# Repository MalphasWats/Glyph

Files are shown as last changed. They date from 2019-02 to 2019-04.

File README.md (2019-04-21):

# Glyph

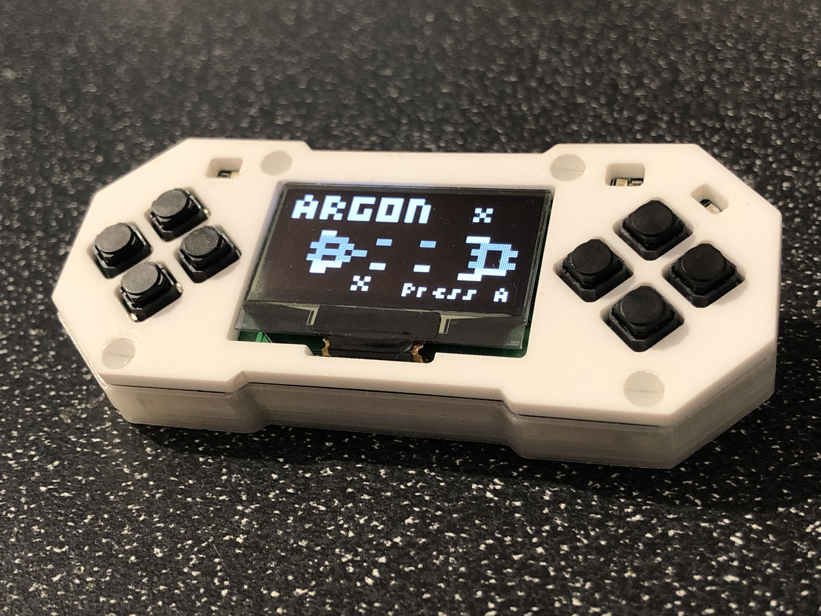
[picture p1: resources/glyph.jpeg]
Glyph


Glyph is a handheld gaming device based on the ATMega1284P micro controller.

This repository contains the mechanical components - KiCAD PCB & laser cut case.

## Specification

* ATMega1284P @ 16MHz. 128kB Flash, 16kB SRAM
* 1.3" monochrome OLED display
* 8 soft buttons
* 2 channel sound via piezo speaker
* 2 programmable red LEDs

## PCB

[KiCAD symbol/footprint library][KiLIB]

## Code

A software library for controlling the hardware and building simple games is available here:

[glyphlib][GLYPHLIB]

## Games

* [Argon][ARGON]
* ... more soon

[GLYPH]: resources/glyph.jpeg
[GLYPHLIB]: https://github.com/MalphasWats/glyphlib
[ARGON]: https://github.com/MalphasWats/Argon
[KiLIB]: https://github.com/MalphasWats/KiCADLib

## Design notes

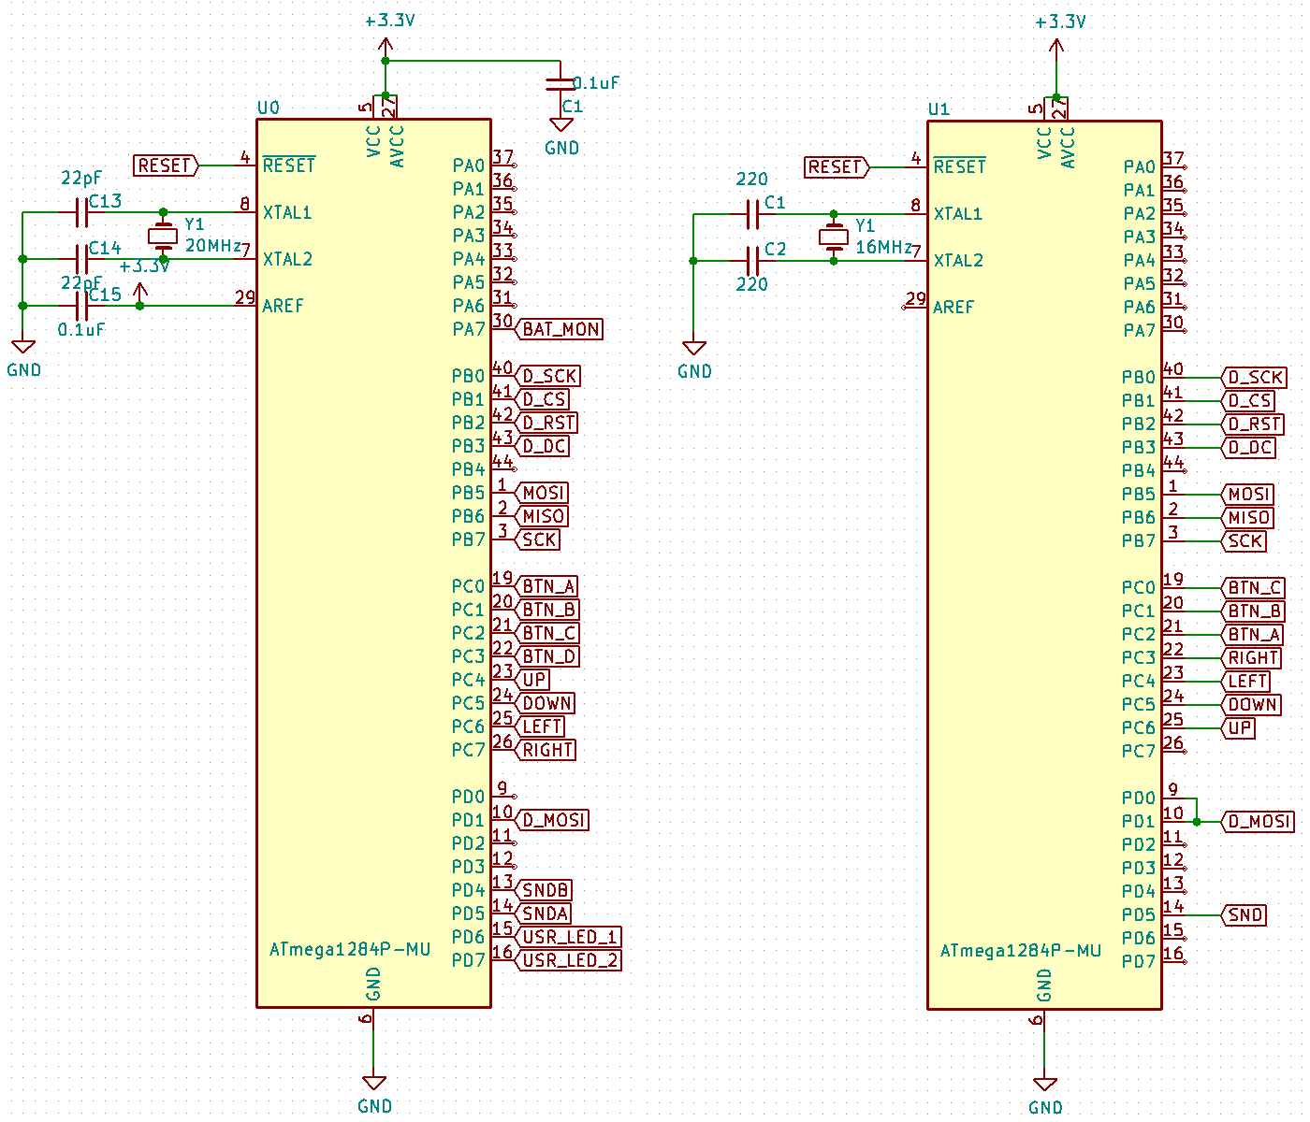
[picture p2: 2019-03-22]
resources/pin-diffs.png

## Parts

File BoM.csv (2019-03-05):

Id | Designator | Package | Quantity | Designation | Supplier and ref
1 | SW9 | ALPS-SSSS811101_SPDT | 1 | POWER
2 | J1 | ISP_SMD | 1 | ISP
3 | U1 | 1.3-OLED-bare-noslot | 1 | 1.3-OLED
4 | SW7 | SW_SOFT_SMD_6mm | 1 | BTN_C
5 | SW0 | SW_SOFT_SMD_6mm | 1 | RESET
6 | SW1 | SW_SOFT_SMD_6mm | 1 | UP
7 | SW2 | SW_SOFT_SMD_6mm | 1 | DOWN
8 | SW3 | SW_SOFT_SMD_6mm | 1 | LEFT
9 | SW4 | SW_SOFT_SMD_6mm | 1 | RIGHT
10 | SW5 | SW_SOFT_SMD_6mm | 1 | BTN_A
11 | SW6 | SW_SOFT_SMD_6mm | 1 | BTN_B
12 | J2 | USB_Micro-B_Molex-105017-0001 | 1 | USB-Micro
13 | LS1 | Generic_Speaker | 1 | Speaker
14 | U2 | SOT-23-5_HandSoldering | 1 | CHG CTRL
15 | U3 | SOT-23_Handsoldering | 1 | Reg
16 | J3 | M2_SCREW_HOLE | 1 | Screw Point 1
17 | J4 | M2_SCREW_HOLE | 1 | Screw Point 2
18 | J5 | M2_SCREW_HOLE | 1 | Screw Point 3
19 | J6 | M2_SCREW_HOLE | 1 | Screw Point 4
20 | SW8 | SW_SOFT_SMD_6mm | 1 | BTN_D
21 | J0 | 150mAh-Lipo | 1 | Battery Pads
22 | C2,C3,C4,C10,C11 | C_0805_2012Metric | 5 | 1uF
23 | C5,C6 | C_0805_2012Metric | 2 | 4.7uF
24 | C7,C12 | C_0805_2012Metric | 2 | 0.1uF
25 | C8 | C_0805_2012Metric | 1 | 47uF
26 | C9 | C_0805_2012Metric | 1 | 22uF
27 | D1 | LED_0805_2012Metric | 1 | USR_1
28 | D2 | LED_0805_2012Metric | 1 | USR_2
29 | R0 | R_0805_2012Metric | 1 | 1K
30 | R1,R6,R7 | R_0805_2012Metric | 3 | LED
31 | R2 | R_0805_2012Metric | 1 | 2K
32 | R3,R4 | R_0805_2012Metric | 2 | 10M
33 | R5 | R_0805_2012Metric | 1 | 290k
34 | C1,C15 | C_0805_2012Metric_Pad1.15x1.40mm_HandSolder | 2 | 0.1uF
35 | C13,C14 | C_0805_2012Metric_Pad1.15x1.40mm_HandSolder | 2 | 22pF
36 | D0 | LED_0805_2012Metric | 1 | CHG
37 | U0 | TQFP-44_10x10mm_P0.8mm | 1 | ATmega1284P-MU
38 | Y1 | Crystal_SMD_5032-2Pin_5.0x3.2mm | 1 | 20MHz

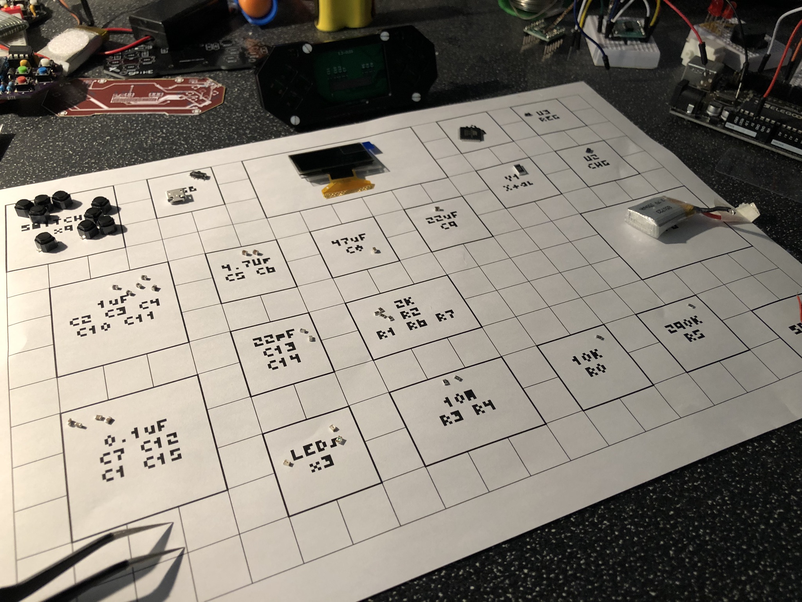
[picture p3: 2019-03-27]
resources/parts.jpeg

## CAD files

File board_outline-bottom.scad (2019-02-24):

module spike()
{
    minkowski()
    {
        union()
        {
            rotate([0, 0, 360/16]) circle(r=18, $fn=8);
            translate([50, 0, 0]) rotate([0, 0, 360/16]) circle(r=18, $fn=8);
            translate([25, 0]) square([32, 30], center=true);
        }
        circle(r=1, $fn=60);
    }
}

module shard()
{
    union()//difference()
    {
        minkowski()
        {
            square([30, 20], center=true);
            circle(r=1, $fn=30);
        }
        
    }
    
    translate([0, 14 , 0]) 
    difference()
    {
        color("red") square([17.26, 7], center=true);
        
        translate([17.26/2, 3.5])rotate([0, 0, 45]) 
        {
            square(1.5, center=true);
        }
        translate([-17.26/2, 3.5]) rotate([0, 0, 45])
        {
            square(1.5, center=true);
        }
    }
}

hole_size = 2 + 0.1;

difference()
{
    scale([1.0, 1.0]) translate([-25, 0]) spike();
    
    
    translate([-19, 15]) circle(d=hole_size, $fn=30);
    translate([19, 15]) circle(d=hole_size, $fn=30);
    
    translate([-31, -15]) circle(d=hole_size, $fn=30);
    translate([31, -15]) circle(d=hole_size, $fn=30);
    
    // Battery
    translate([0, 0]) minkowski()
    {
        square([30, 24], center=true);
        circle(d=1, $fn=30);
    }
    
    /* USB */
    translate([36, 10.5]) rotate([0, 0, 45]) minkowski()
    {
        square([5, 8], center=true);
        circle(r=0.5, $fn=30);
    }
    
    // Speaker
    translate([-28, 0]) circle(r=7, $fn=30);
    translate([-28, -7]) square([4, 4], center=true);
    
    // power
    translate([-36, 11]) rotate([0, 0, 45]) minkowski()
    {
        square([8, 4], center=true);
        circle(d=2, center=true, $fn=30);
    }
    
    //reset
    translate([-20, -10]) minkowski()
    {
        square([5, 5], center=true);
        circle(r=0.5, $fn=30);
    }
    
    //ICs
    translate([23, 0]) minkowski()
    {
        hull()
        {
            square([10, 22], center=true);
            translate([8.5, -3]) square([5, 16], center=true);
        }
        circle(r=0.5, $fn=30);
    }
    
    //ISP
    translate([-25, 14]) minkowski()
    {
        square([7, 4.5], center=true);
        circle(r=0.5, $fn=30);
    }
}

//color("green") translate([27, -2]) square([15, 18], center=true);

//color("red") translate([0, 8, -1.1]) rotate([0, 0, 180]) shard();

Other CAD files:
board_outline-top.scad
board_outline.scad
case-bottom.scad
case/case-3dp.scad
case/case-bottom-01.scad
case/case-bottom.scad
case/case-top-3dp.scad
case/case-top-engrave.scad
case/case-top.scad
glyph-isp/glyph-isp_outline.scad

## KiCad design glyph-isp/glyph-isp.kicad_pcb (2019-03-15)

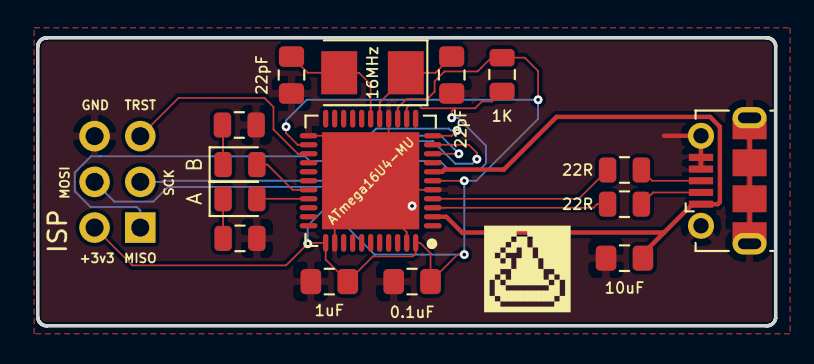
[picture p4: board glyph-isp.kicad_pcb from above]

Board: 2 copper layers, 41.0 x 16.0 mm, 18 parts (1 on the bottom side), 18 nets.

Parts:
C0: 0.1uF; C_0805_2012Metric_Pad1.15x1.40mm_HandSolder
C1, C2: 22pF; C_0805_2012Metric_Pad1.15x1.40mm_HandSolder
C3: 1uF; C_0805_2012Metric_Pad1.15x1.40mm_HandSolder
C4: 10uF; C_0805_2012Metric_Pad1.15x1.40mm_HandSolder
D1: LED1; LED_0805_2012Metric
D2: LED2; LED_0805_2012Metric
HAT: HAT
J0, J1: ISP; PinHeader_2x03_P2.54mm_Vertical
J2: USB-Micro; USB_Micro-B_Molex-105017-0001
R1: 1K; R_0805_2012Metric
R2, R3: LED; R_0805_2012Metric
R4, R5: 22R; R_0805_2012Metric
U0: ATmega16U4-MU; QFN-44-1EP_7x7mm_P0.5mm_EP5.4x5.4mm
Y1: 16MHz; Crystal_SMD_5032-2Pin_5.0x3.2mm

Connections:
+3V3: C0.1, C3.1, J0.2, J1.2, R1.1, U0.6, U0.14, U0.24, U0.34, U0.44
D+: R4.1, U0.4
D-: R5.1, U0.3
GND: C0.2, C1.2, C2.2, C3.2, C4.1, J0.6, J1.6, J2.4, J2.5, J2.6, R2.2, R3.2, U0.5, U0.15, U0.23, U0.35, U0.43, U0.45
LED1: D1.2, U0.29
LED2: D2.2, U0.30
MISO: J0.1, J1.1, U0.11
MOSI: J0.4, J1.4, U0.10
unnamed: C1.1, U0.17, Y1.2
unnamed: C2.1, U0.16, Y1.1
unnamed: D1.1, R2.1
unnamed: D2.1, R3.1
unnamed: J2.2, R5.2
unnamed: J2.3, R4.2
RESET: J0.5, R1.2, U0.13
SCK: J0.3, J1.3, U0.9
TARGET_RESET: J1.5, U0.25
VBUS: C4.2, J2.1, U0.2, U0.7

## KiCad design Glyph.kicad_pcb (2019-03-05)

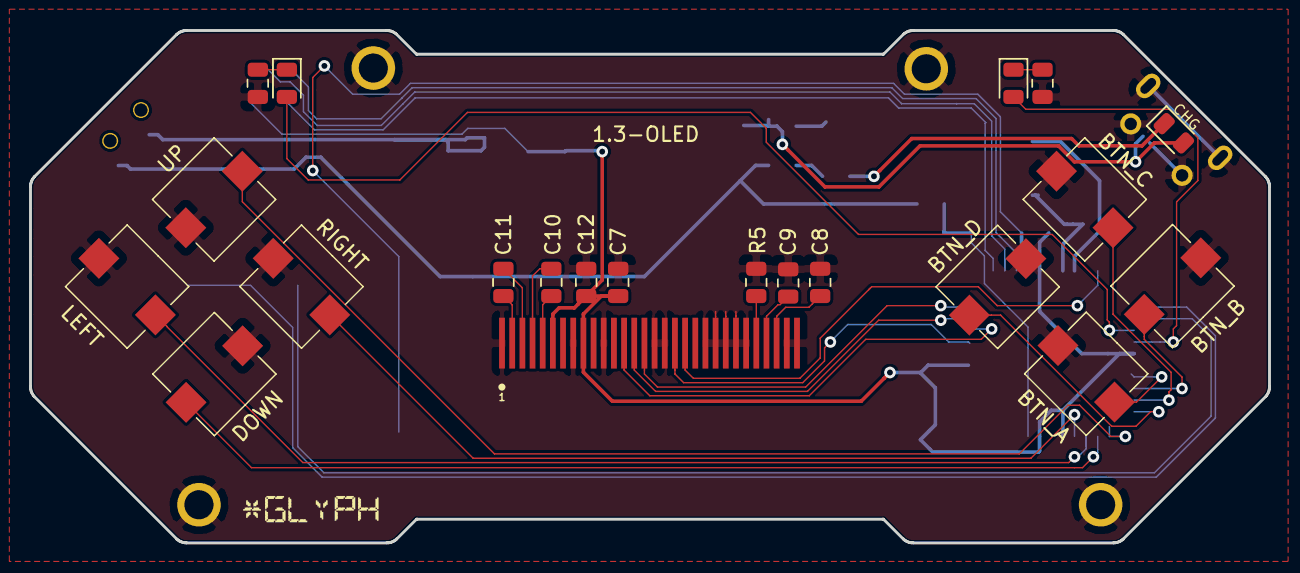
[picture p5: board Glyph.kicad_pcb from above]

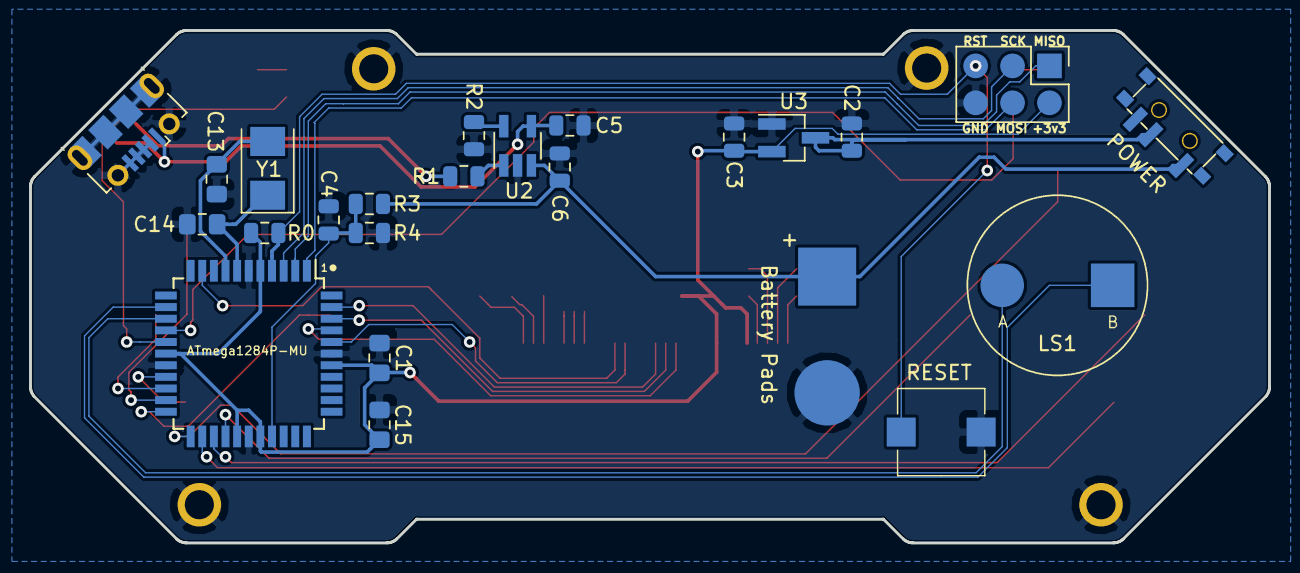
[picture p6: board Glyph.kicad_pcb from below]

Board: 2 copper layers, 85.3 x 35.3 mm, 50 parts (24 on the bottom side), 41 nets.

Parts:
C1, C15: 0.1uF; C_0805_2012Metric_Pad1.15x1.40mm_HandSolder
C2, C3, C4, C10, C11: 1uF; C_0805_2012Metric
C5, C6: 4.7uF; C_0805_2012Metric
C7, C12: 0.1uF; C_0805_2012Metric
C8: 47uF; C_0805_2012Metric
C9: 22uF; C_0805_2012Metric
C13, C14: 22pF; C_0805_2012Metric_Pad1.15x1.40mm_HandSolder
D0: CHG; LED_0805_2012Metric
D1: USR_1; LED_0805_2012Metric
D2: USR_2; LED_0805_2012Metric
J0: Battery Pads; 150mAh-Lipo
J1: ISP; ISP_SMD
J2: USB-Micro; USB_Micro-B_Molex-105017-0001
J3: Screw Point 1; M2_SCREW_HOLE
J4: Screw Point 2; M2_SCREW_HOLE
J5: Screw Point 3; M2_SCREW_HOLE
J6: Screw Point 4; M2_SCREW_HOLE
LOGO: LOGO
LS1: Speaker; Generic_Speaker
R0: 1K; R_0805_2012Metric
R1, R6, R7: LED; R_0805_2012Metric
R2: 2K; R_0805_2012Metric
R3, R4: 10M; R_0805_2012Metric
R5: 290k; R_0805_2012Metric
SW0: RESET; SW_SOFT_SMD_6mm
SW1: UP; SW_SOFT_SMD_6mm
SW2: DOWN; SW_SOFT_SMD_6mm
SW3: LEFT; SW_SOFT_SMD_6mm
SW4: RIGHT; SW_SOFT_SMD_6mm
SW5: BTN_A; SW_SOFT_SMD_6mm
SW6: BTN_B; SW_SOFT_SMD_6mm
SW7: BTN_C; SW_SOFT_SMD_6mm
SW8: BTN_D; SW_SOFT_SMD_6mm
SW9: POWER; ALPS-SSSS811101_SPDT
U0: ATmega1284P-MU; TQFP-44_10x10mm_P0.8mm
U1: 1.3-OLED; 1.3-OLED-bare-noslot
U2: CHG CTRL; SOT-23-5_HandSoldering
U3: Reg; SOT-23_Handsoldering
Y1: 20MHz; Crystal_SMD_5032-2Pin_5.0x3.2mm

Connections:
+3V3: C1.2, C3.1, C7.1, C12.1, C15.1, J1.2, R0.1, U0.5, U0.17, U0.27, U0.29, U0.38, U1.6, U1.9, U3.2
+BATT: C6.1, J0.1, R3.1, SW9.1, U2.3
BAT_MON: C4.1, R3.2, R4.1, U0.30
BTN_A: SW5.2, U0.19
BTN_B: SW6.2, U0.20
BTN_C: SW7.2, U0.21
BTN_D: SW8.2, U0.22
CHARGE: C5.1, D0.2, J2.1, U2.4
DOWN: SW2.2, U0.24
D_CS: U0.41, U1.13
D_DC: U0.43, U1.15
D_MOSI: U0.10, U1.19
D_RST: U0.42, U1.14
D_SCK: U0.40, U1.18
GND: C1.1, C2.2, C3.2, C4.2, C5.2, C6.2, C7.2, C8.2, C9.2, C12.2, C13.2, C14.2, C15.2, J0.2, J1.6, J2.2, J2.3, J2.4, J2.5, J2.6, J3.1, J4.1, J5.1, J6.1, R2.2, R4.2, R5.2, R6.2, R7.2, SW0.1, SW1.1, SW2.1, SW3.1, SW4.1, SW5.1, SW6.1, SW7.1, SW8.1, U0.6, U0.18, U0.28, U0.39, U1.1, U1.8, U1.11, U1.16, U1.17, U1.21, U1.22, U1.23, U1.24, U1.25, U1.29, U1.30, U2.2, U3.1
LEFT: SW3.2, U0.25
MISO: J1.1, U0.2
MOSI: J1.4, U0.1
unnamed: C2.1, SW9.2, U3.3
unnamed: C8.1, U1.28
unnamed: C9.1, U1.27
unnamed: C10.1, U1.4
unnamed: C10.2, U1.5
unnamed: C11.1, U1.2
unnamed: C11.2, U1.3
unnamed: C13.1, U0.8, Y1.2
unnamed: C14.1, U0.7, Y1.1
unnamed: D0.1, R1.2
unnamed: D1.1, R6.1
unnamed: D2.1, R7.1
unnamed: R1.1, U2.1
unnamed: R2.1, U2.5
unnamed: R5.1, U1.26
RESET: J1.5, R0.2, SW0.2, U0.4
RIGHT: SW4.2, U0.26
SCK: J1.3, U0.3
SNDA: LS1.2, U0.14
SNDB: LS1.1, U0.13
UP: SW1.2, U0.23
USR_LED_1: D1.2, U0.15
USR_LED_2: D2.2, U0.16

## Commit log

2019-02-01 Initial layout
    [Glyph.kicad_pcb, Glyph.sch, board_outline-bottom.scad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]
2019-02-01 1.3-inch works better
    [board_outline-top.scad]
2019-02-04 initial oled components
    [Glyph.kicad_pcb, Glyph.sch, board_outline-bottom.scad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]
2019-02-05 added OLED circuit
    [Glyph.kicad_pcb, Glyph.sch, board_outline-top.scad]
2019-02-05 forgot to save it
    [board_outline.scad]
2019-02-08 update layout
    [Glyph.kicad_pcb, board_outline-bottom.scad]
2019-02-08 new layout & traces
    [Glyph.kicad_pcb, Glyph.sch, board_outline-bottom.scad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]
2019-02-10 tracks laid out
    [Glyph.kicad_pcb, Glyph.sch, board_outline.scad]
2019-02-10 1284 Shard initial design
    [shard.kicad_pcb, shard.sch, shard_outline.scad]
2019-02-20 initial rework for no shard
    [Glyph.kicad_pcb, Glyph.sch, board_outline-bottom.scad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]
2019-02-23 onboard isp
    [Glyph.sch]
2019-02-24 retuned to fixed MCU
    [Glyph.kicad_pcb, Glyph.sch, board_outline-bottom.scad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]
2019-02-24 moved a thing slightly
    [Glyph.kicad_pcb, board_outline-bottom.scad]
2019-02-26 USB-ISP Prototype
    [glyph-isp.kicad_pcb, glyph-isp.sch, glyph-isp_outline.scad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]
2019-03-05 capacitor label consistency
    [BoM.csv, Glyph.kicad_pcb, Glyph.sch]
2019-03-05 capacitor values consistent
    [glyph-isp.kicad_pcb, glyph-isp.sch]
2019-03-05 added logo
    [Glyph.kicad_pcb]
2019-03-12 reworked ISP size
    [glyph-isp.kicad_pcb, glyph-isp.sch, glyph-isp_outline.scad]
2019-03-27 developing case
    [case-bottom-01.scad, case-top-engrave.scad, case-top.scad]
2019-04-12 3D case initial prototype
    [case-3dp.scad]
2019-04-15 tweak tolerance
    [case-3dp.scad]
2019-04-15 fix perimeter
    [case-3dp.scad]
2019-04-15 add speaker holes
    [case-3dp.scad]
2019-04-15 embiggened top to fit 3dp bottom
    [case-top.scad]
2019-04-15 3dp top
    [case-top-3dp.scad]
2019-04-15 3dp top tweak tolerances
    [case-top-3dp.scad]
2019-04-17 Added programming hole
    [case-3dp.scad]
2019-04-21 changed crystal to 16MHz
    [Glyph.sch, case-3dp.scad]
2019-11-23 case tweaks
    [case-3dp.scad, case-top-3dp.scad]
